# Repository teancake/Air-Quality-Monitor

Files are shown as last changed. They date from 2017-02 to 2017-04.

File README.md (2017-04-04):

# Air-Quality-Monitor
Schematic and PCB design of an air quality monitor.

### Description ###
This WiFi switch module utilises the [ESP-12E/F adaptor](https://github.com/teancake/ESP8266-ESP12-Adaptor "ESP-12E/F Adaptor").
### Programs ###
There are two ways of programming this piece of hardware:
1. Program both the AVR chip on the Arduino board and the ESP8266 chip on the ESP-12E/F board.
2. Program only the AVR chip on the Arduino board. 

The first approach is recommended, since it exhibits more flexibility and the program is more structured. For this approach, please refer to 
[Arduino program](https://github.com/teancake/Indoor-Air-Quality-Monitoring-and-Control-System/tree/master/software/sensor_unit_software/officenv_arduino_v2) and [ESP8266 program](https://github.com/teancake/Indoor-Air-Quality-Monitoring-and-Control-System/tree/master/software/sensor_unit_software/officenv_esp12ef_v1) in the [Indoor-Air-Quality-Monitoring-and-Control-System](https://github.com/teancake/Indoor-Air-Quality-Monitoring-and-Control-System) repository, respectively. 

If you insist to use the second approach, please leave the original firmware in the ESP8266 chip as it is and use [Arduino program](https://github.com/teancake/Indoor-Air-Quality-Monitoring-and-Control-System/tree/master/software/sensor_unit_software/officenv_arduino_v1) for the Arduino board. In this way, you may also need a TCP server to receive the data from the sensor, an example of the server program is [here, publish_office_air_quality.py](https://github.com/teancake/Indoor-Air-Quality-Monitoring-and-Control-System/tree/master/software/server_software) in the [Indoor-Air-Quality-Monitoring-and-Control-System](https://github.com/teancake/Indoor-Air-Quality-Monitoring-and-Control-System) repository.

For both approaches, make sure the baud rate of the Arduino and the ESP-12E/F boards are the same. If you use the second approach, the default baud rate of the ESP-12 board is 115200, which can be changed (say to 57600) using an AT command as `AT+CIOBAUD=57600` and checked by `AT+CIOBAUD?`. I was not successful at changing the baud rate of the ESP-12 board, but was successful on an ESP-03 board. Besides, the baud rate of 115200 was exceedingly unreliable between Arduino Pro Mini 3.3V version and ESP8266, and I have to reduce it to at most 57600 in order to make the communication work. I had no idea of why these mysteries happened, so if anybody finds the reason, please do let me know.
 
### The Finished Board ###
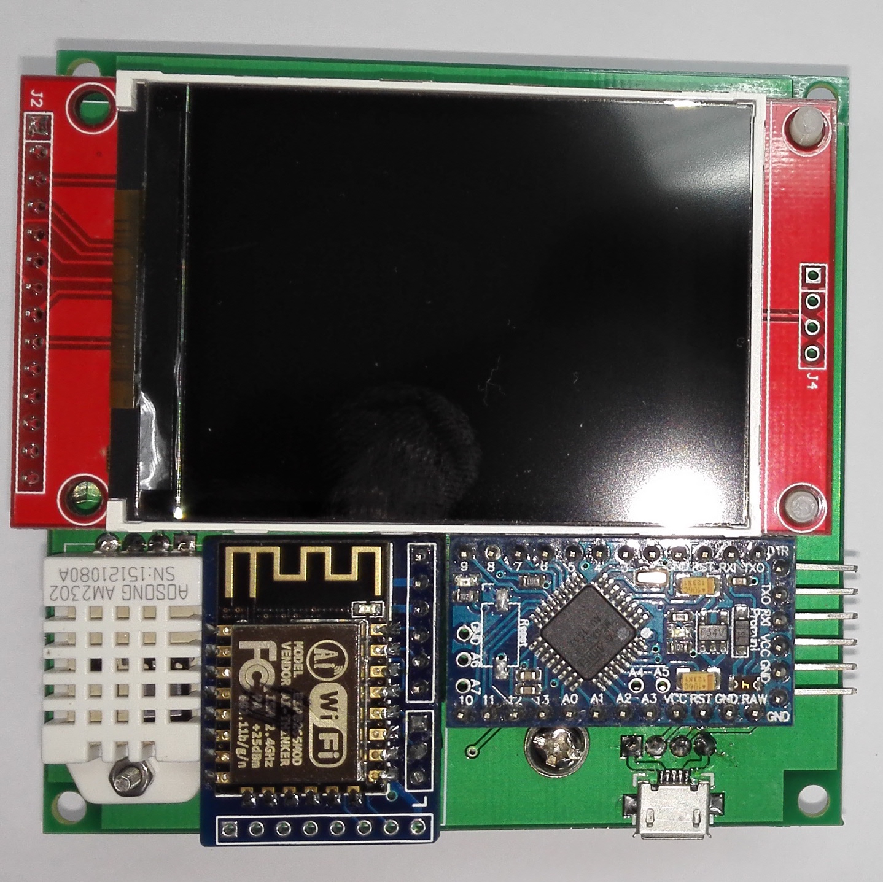
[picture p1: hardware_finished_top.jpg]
 
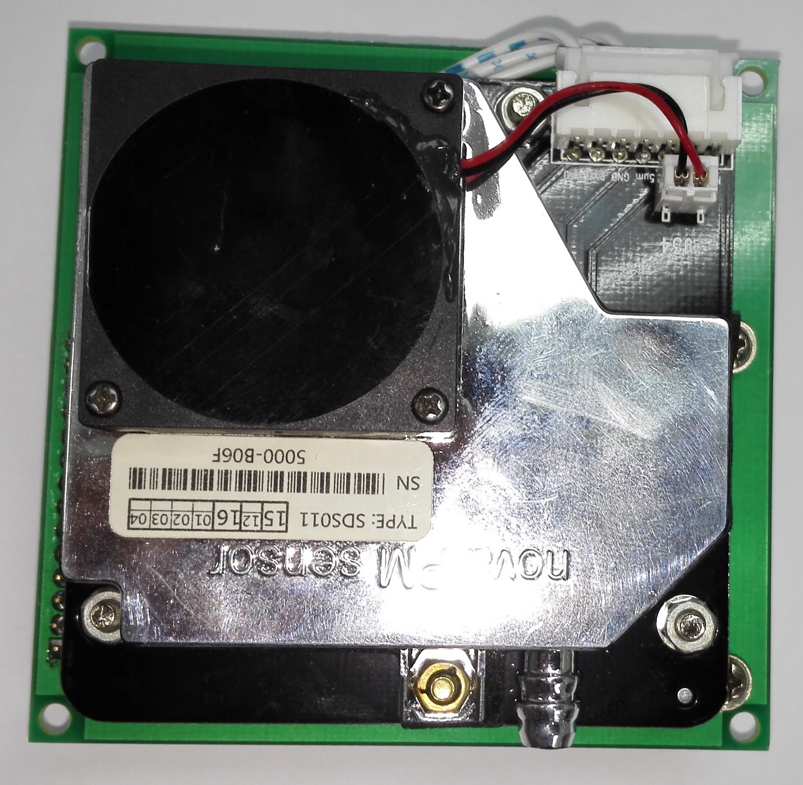
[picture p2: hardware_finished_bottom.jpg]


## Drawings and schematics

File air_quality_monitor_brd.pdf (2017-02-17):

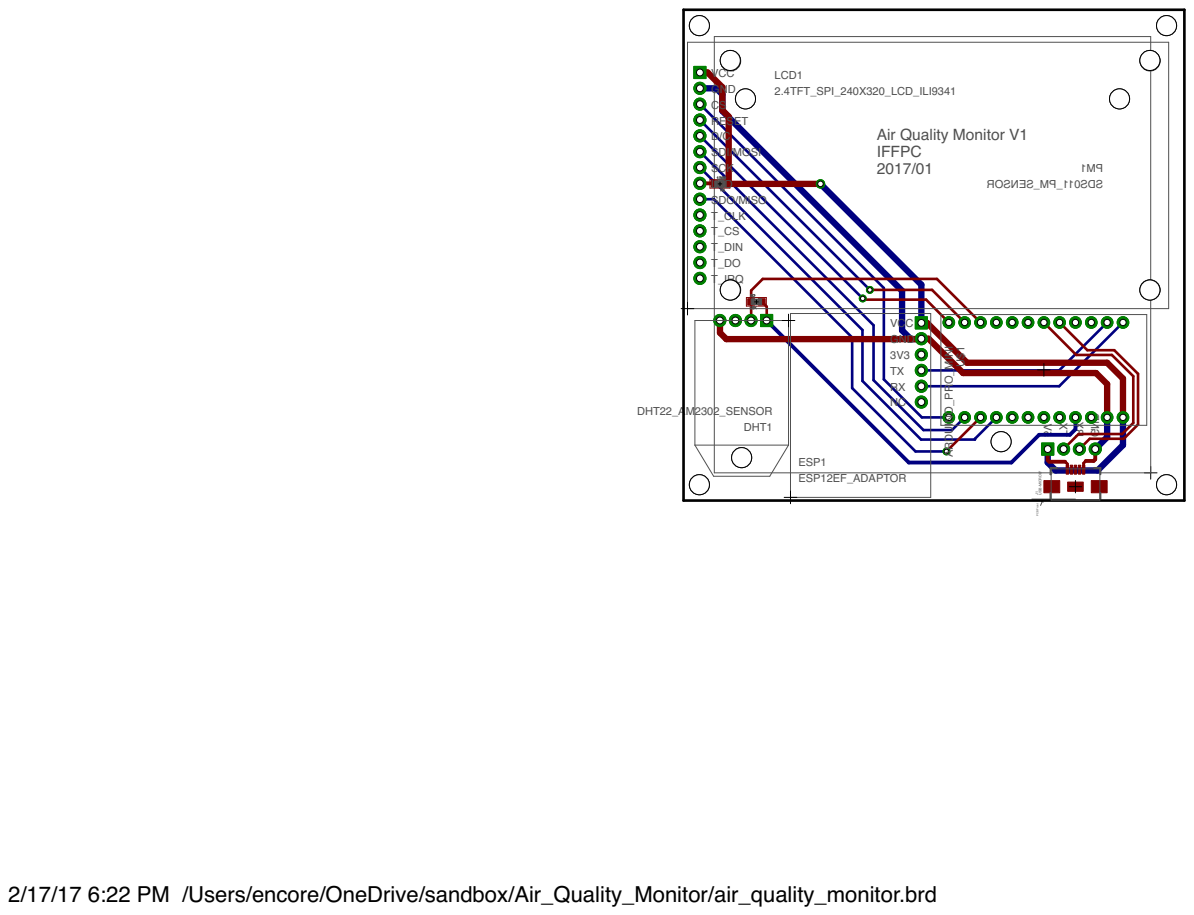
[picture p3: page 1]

2/17/17 6:22 PM /Users/encore/OneDrive/sandbox/Air_Quality_Monitor/air_quality_monitor.brd

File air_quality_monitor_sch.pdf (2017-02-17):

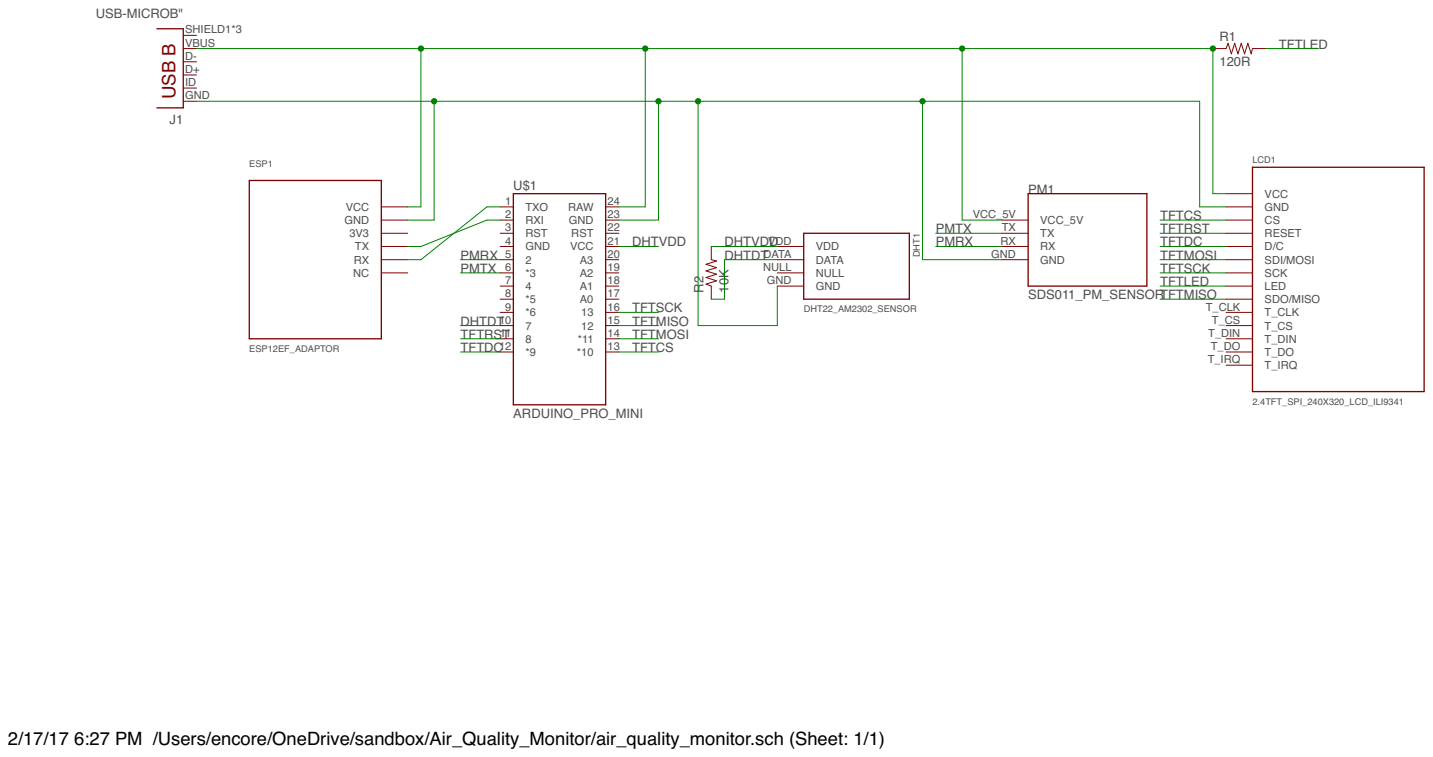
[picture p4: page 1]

2/17/17 6:27 PM /Users/encore/OneDrive/sandbox/Air_Quality_Monitor/air_quality_monitor.sch (Sheet: 1/1)

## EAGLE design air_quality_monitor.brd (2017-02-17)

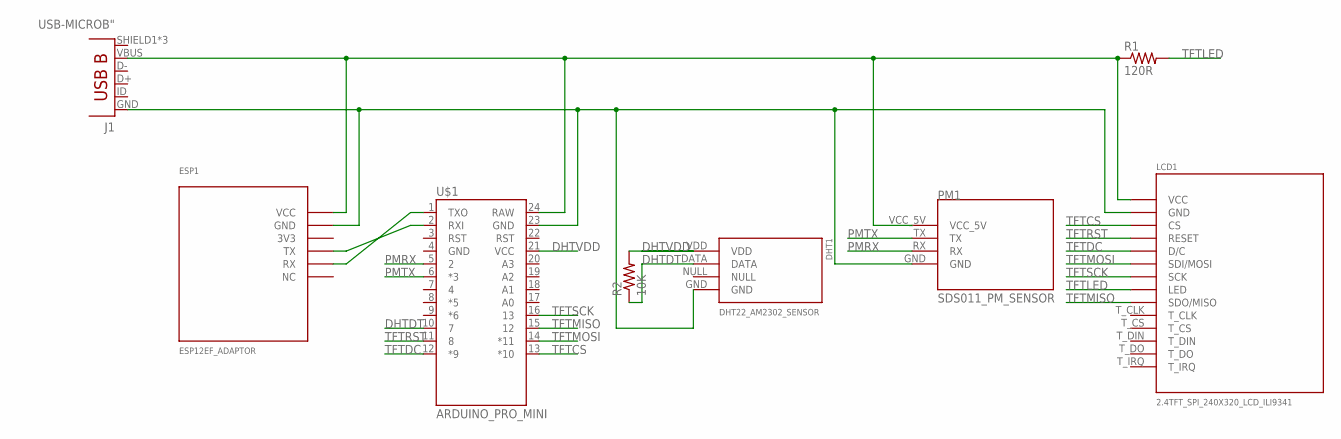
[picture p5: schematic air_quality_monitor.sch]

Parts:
DHT1: DHT22_AM2302_SENSOR
ESP1: ESP12EF_ADAPTOR
J1: USB-MICROB"; USB-B-MICRO-SMD_V03
LCD1: 2.4TFT_SPI_240X320_LCD_ILI9341
PM1: SDS011_PM_SENSOR
R1: 120R; 0603-RES
R2: 10K; 0603-RES
U$1: ARDUINO_PRO_MINI

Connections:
DHTDT: DHT1.DATA, R2.1, U$1.10 (7)
DHTVDD: DHT1.VDD, R2.2, U$1.21 (VCC)
unnamed: DHT1.GND, ESP1.GND, J1.GND, LCD1.GND, PM1.GND, U$1.23 (GND)
unnamed: ESP1.VCC, J1.VBUS, LCD1.VCC, PM1.VCC_5V, R1.1, U$1.24 (RAW)
unnamed: ESP1.TX, U$1.2 (RXI)
unnamed: ESP1.RX, U$1.1 (TXO)
PMRX: PM1.RX, U$1.5 (2)
PMTX: PM1.TX, U$1.6 (*3)
TFTCS: LCD1.CS, U$1.13 (*10)
TFTDC: LCD1.D/C, U$1.12 (*9)
TFTLED: LCD1.LED, R1.2
TFTMISO: LCD1.SDO/MISO, U$1.15 (12)
TFTMOSI: LCD1.SDI/MOSI, U$1.14 (*11)
TFTRST: LCD1.RESET, U$1.11 (8)
TFTSCK: LCD1.SCK, U$1.16 (13)

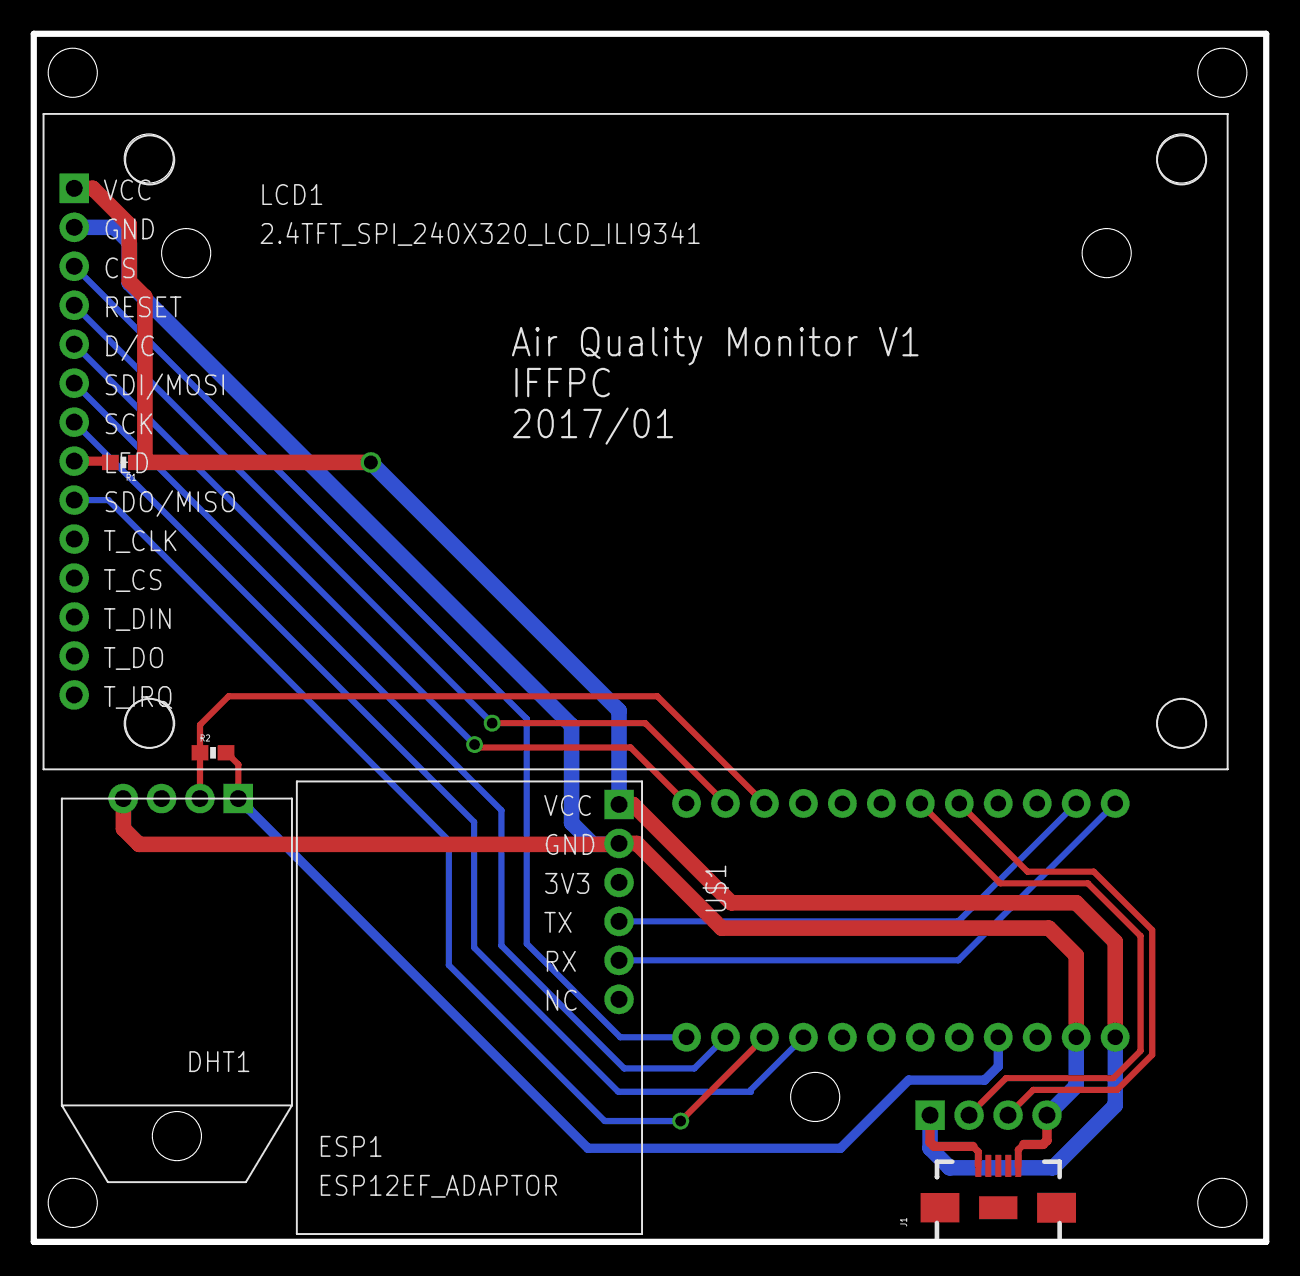
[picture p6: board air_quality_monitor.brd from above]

Board: 2 copper layers, 80.3 x 78.7 mm, 8 parts (1 on the bottom side), 15 nets.

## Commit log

2017-02-17 initial release
    [air_quality_monitor.brd, air_quality_monitor.sch]
2017-02-27 add finished board and modify readme accordingly
